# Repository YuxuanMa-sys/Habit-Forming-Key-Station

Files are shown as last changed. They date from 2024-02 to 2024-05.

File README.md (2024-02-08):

# Habit Forming Key Station

# Problem

People have a difficult time building habits. Specifically, a common issue that many have is losing or misplacing their keys/wallet whenever they enter their place of residence. If they were accustomed to placing and grabbing their keys from a specific designated location, then the likelihood of losing their keys and wallet would be significantly low.

# Solution

Our solution utilizes negative reinforcement to build positive habits for its users. We will build a designated station for placing one’s keys, or any small item of their choosing, when entering or leaving their home. It will begin detecting the proximity of the keys a few minutes after the keys have initially been removed from the dish, indicating the resident is not home. Once the resident returns home with the keys, a sensor should detect its presence with an RFID tag and continue ringing an alarm through a speaker until the keys are placed correctly. There will be a pressure sensor at the bottom of the dish that will indicate whether the keys have been put into the device. Our solution will have 5 subsystems: proximity detection, control and processing, alarm, confirmation, and power. 

Team members:

- [Ali Husain]
- [Cedric Mathew]
- [Marsh Ma]

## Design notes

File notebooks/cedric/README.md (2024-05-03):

### Lab Entry: February 17, 2024 - Power Subsystem Initial Design and Testing
**Objective:** Design and test the Power Subsystem to ensure stable voltage supply for all components.

**Design Considerations:**
- Chose a power adapter capable of delivering 5V to 36V to accommodate various component needs.
- Integrated a voltage regulator (LM1117T-3.3) to step down voltage to 3.3V, necessary for microcontroller and sensor operations.

**Equations and Formulas:**
- Voltage Output: \( V_{out} = V_{in} \times \left(\frac{R2}{R1 + R2}\right) \) where \( V_{in} \) is the input from the power adapter, R1 and R2 are resistances in the voltage divider circuit.
  
**Bibliographic References:**
- LM1117 800-mA Low-Dropout Linear Regulator Datasheet, Texas Instruments. [Accessed: February 17, 2024].

**Testing and Debugging:**
- Setup included the power adapter connected to a breadboard with multimeter readings confirming output stability.
- Identified an issue with voltage fluctuation; added capacitors to stabilize output.

**Results and Analysis:**
- Post modification, stable 3.3V output achieved with ±0.05V tolerance.
- Test setup and multimeter readings documented for future reference.

### Lab Entry: February 28, 2024 - Alarm Subsystem Initial Design and Testing
**Objective:** Design and test the Alarm Subsystem to ensure it triggers appropriately when the user does not place keys in the designated area.

**Design Considerations:**
- Selected CMS-251472-24SP speaker for its optimal sound pressure level and frequency response for household environments.
- Integrated with ATtiny84A microcontroller to manage alarm logic based on input from the proximity detection subsystem.

**Equations and Formulas:**
- Sound Pressure Level (SPL) calculation to ensure audibility: \( SPL = 20 \log \left(\frac{P}{P_{ref}}\right) \) where \( P \) is the sound pressure and \( P_{ref} \) is the reference sound pressure.

**Bibliographic References:**
- CMS-251472-24SP Datasheet, CUI Devices. [Accessed: February 24, 2024].

**Testing and Debugging:**
- Alarm subsystem circuit set up on breadboard with connections to microcontroller and speaker.
- Tested alarm activation by simulating conditions where keys are not placed: alarm triggered as expected.

**Results and Analysis:**
- Alarm effectively audible at 80 dB across standard testing room, conforming to design specifications.
- Documented all testing setups, circuit diagrams, and results for inclusion in the final report.

### Lab Entry: March 21, 2024 - Further Testing of the Power Subsystem
**Objective:** Conduct extensive load testing on the Power Subsystem to ensure reliability under full operational conditions.

**Design Considerations:**
- Continued use of the initial power adapter and voltage regulator setup to evaluate long-term stability and performance under variable loads.

**Equations and Formulas:**
- Calculation of expected power draw: \( P = V \times I \), ensuring that total power does not exceed the capacity of the power adapter.

**Bibliographic References:**
- "Understanding Power Supplies and Simple Circuits," IEEE Spectrum, 2024. Provides insights into best practices for power stability and efficiency.

**Testing and Debugging:**
- Setup included multiple components drawing power simultaneously to simulate real-world usage.
- Monitored voltage drops and regulator heat dissipation over extended periods.

**Results and Analysis:**
- Observed minimal voltage fluctuation within acceptable limits of ±0.1V during extended testing.
- Heat dissipation was within safe limits; however, noted the need for potential heat sinks if ambient temperatures increase.

### Lab Entry: March 30, 2024 - Prototype Housing Development and Testing
**Objective:** Design and test a prototype housing for the key station to enhance aesthetic appeal and functional reliability.

**Design Considerations:**
- Explore materials that are both aesthetically pleasing and functional, such as acrylic and ABS plastic, for the prototype housing.
- Design must accommodate all internal components securely while allowing easy access for maintenance and adjustments.

**Bibliographic References:**
- "Modern Materials for Product Design," Materials Today, 2024. Discusses the properties of various polymers and composites used in consumer electronics housing.

**Testing and Debugging:**
- Constructed an initial prototype using 3D-printed ABS plastic to assess fit and ease of assembly.
- Conducted drop tests and stress tests to evaluate the durability of the materials and the integrity of the housing.

**Results and Analysis:**
- The prototype housing adequately protected internal components from impacts and provided satisfactory thermal management.
- Identified issues with assembly alignment; adjustments to design tolerances were noted for the next prototype iteration.

### Lab Entry: April 6, 2024 - CAD Design Refinement and Component Layout
**Objective:** Refine the CAD design of the key station's housing to optimize space and improve component arrangement.

**Design Considerations:**
- Utilize CAD software to create detailed 3D models of the housing, ensuring all components fit precisely with efficient use of space.
- Design features such as snap-fit connections for easier assembly and maintenance.

**Equations and Formulas:**
- Calculation of enclosure dimensions based on component sizes and necessary clearances: \( V = l \times w \times h \) where \( l, w, h \) are the length, width, and height of the housing.

**Bibliographic References:**
- "CAD Techniques in Modern Product Design," Journal of Engineering and Industrial Design, 2024. Discusses advanced CAD modeling strategies for electronic enclosures.

**Testing and Debugging:**
- Digital simulations of the assembly process to identify potential interference or alignment issues.
- Stress analysis on critical points to ensure the structure can withstand everyday use.

**Results and Analysis:**
- Adjustments made to the internal layout to reduce interference and improve airflow around heat-generating components.
- Identified the need for additional supports around the snooze button and speaker areas to prevent flexing during use.

### Lab Entry: April 9, 2024 - Prototype Iteration and User Interface Design
**Objective:** Iterate on the prototype design based on initial feedback and integrate user interface elements for better usability.

**Design Considerations:**
- Enhance the visual and tactile aspects of the user interface, such as the snooze button and LED indicators, using CAD to model these features precisely.
- Incorporate feedback mechanisms visually represented in the CAD model to assist with user interaction.

**Bibliographic References:**
- "Ergonomics in Design: User Interface and Aesthetics," Human Factors and Ergonomics, 2024. Provides guidelines for designing user-friendly interfaces and controls.

**Testing and Debugging:**
- Conduct user testing with the new prototype to gather feedback on the interface and overall usability.
- Use CAD simulations to visualize operation sequences and ensure all moving parts operate without binding.

**Results and Analysis:**
- User feedback highlighted the need for larger, more tactile buttons and clearer LED indicators, which were incorporated into the design.
- CAD revisions made to improve ergonomics, reducing the force required to activate controls and enhancing user interaction comfort.

### Lab Entry: April 15, 2024 - Final Power System Redesign
**Objective:** Implement a final redesign of the Power Subsystem due to issues with the original power adapter and to accommodate changes in voltage requirements.

**Design Considerations:**
- Switched to using an Arduino Uno as a stable 5V power source after the power adapter failed to provide consistent outputs.
- Adjusted voltage requirements across subsystems to ensure compatibility with the Arduino's output capabilities.

**Equations and Formulas:**
- Verification of power supply requirements: \( I = \frac{P}{V} \), where \( P \) is power in watts, \( V \) is voltage in volts, and \( I \) is current in amperes. This equation ensures that the Arduino can sufficiently power all subsystems without exceeding its current limitations.

**Bibliographic References:**
- Arduino Power Supply Capabilities, Arduino Official Documentation, 2024.

**Testing and Debugging:**
- Re-tested the entire system using the Arduino to ensure all subsystems function correctly with the new power setup.
- Monitored system stability and temperature to assess the impact of continuous operation on the Arduino.

**Results and Analysis:**
- The Arduino provided a stable and reliable power source, with all subsystems operating within normal parameters.
- Noted improvements in system reliability and a reduction in complexity by eliminating the external power adapter.

### Lab Entry: April 17, 2024 - Final System Assembly and Verification Testing
**Objective:** Assemble the final version of the habit-forming key station and conduct comprehensive verification testing to validate all design requirements and functionality.

**Design Considerations:**
- Integrated all subsystems within the newly designed housing, ensuring secure mounting and optimal placement for user interaction.
- Enhanced the alarm subsystem by switching from a traditional speaker to a piezo buzzer for better reliability and integration on the breadboard setup.

**Bibliographic References:**
- "Standards for Electronic Test and Verification," IEEE Standard Association, 2024.

**Testing and Debugging:**
- Conducted a series of stress tests, including power cycling and long-duration operational tests, to ensure durability and reliability.
- Systematic testing of the proximity detection, alarm functionality, and user interface responsiveness.

**Results and Analysis:**
- All subsystems met or exceeded their performance criteria, with successful integration demonstrated through seamless operation during testing.
- Feedback from user trials was overwhelmingly positive, with particular praise for the system's responsiveness and reliability.

**Additional Notes:**
- Prepared detailed documentation of all tests, including setups, results, and any anomalies, for inclusion in the final project report.
- Developed a user manual based on the testing outcomes and operational characteristics of the key station.

## Lab Entry: April 20, 2024 - Preparation of Presentation and Final Paper Outlines
### Objective
Develop comprehensive outlines for an upcoming presentation and the final project report, summarizing the project's scope, key findings, and conclusions.

### Design Considerations
- Organize content to flow logically, beginning with an introduction to the problem statement, followed by a detailed discussion of the design process, testing methodologies, and final outcomes.
- Emphasize key innovations, challenges overcome, and the practical applications of the habit-forming key station.

### Presentation Outline
1. **Introduction**
   - Overview of the project and its objectives.
   - Importance of key management and habit formation.

2. **Design Overview**
   - Description of the habit-forming key station and its components.
   - Detailed view of the subsystems: Power, Alarm, Proximity Detection, and Confirmation.

3. **Testing and Results**
   - Summary of testing phases for each subsystem.
   - Presentation of critical data and findings.
   - Discussion on the stability and efficiency improvements in the final design.

4. **Challenges and Solutions**
   - Highlight significant challenges faced during the design and testing phases.
   - Discuss the solutions implemented to overcome these challenges.

5. **Conclusion and Future Work**
   - Summary of the project’s impact on habitual behavior related to key placement.
   - Suggestions for future enhancements or related products.

6. **Q&A**
   - Open the floor for questions and provide thoughtful responses to engage the audience.

### Final Paper Outline
1. **Abstract**
   - Brief summary of the entire project and its outcomes.

2. **Introduction**
   - Detailed problem statement and the project's scope.

3. **Methodology**
   - Explanation of the design process and testing methodologies used.

4. **System Design**
   - Comprehensive details of each subsystem, including schematics and component specifications.

5. **Results**
   - Analysis of testing results, demonstrating the efficacy of the system.
   - Statistical data and graphs showcasing performance metrics.

6. **Discussion**
   - Interpretation of results.
   - Evaluation of the system’s performance against initial objectives.

7. **Challenges and Solutions**
   - Detailed account of obstacles encountered and their resolutions.

8. **Conclusion and Recommendations**
   - Conclusions drawn from the project.
   - Recommendations for future research and potential product development.

9. **References**
   - Cite all sources used in the research and development of the project.

### Testing and Debugging
- Conduct peer reviews of the outlines to ensure completeness and clarity.
- Simulate the presentation to a small audience for feedback on content delivery and comprehension.

### Results and Analysis
- Adjustments made to the presentation content based on feedback, improving clarity and engagement.
- Finalization of the paper outline to ensure it meets academic standards and thoroughly documents the project lifecycle.

### Additional Notes
- Prepare visual aids and supplementary materials for the presentation to enhance audience understanding.
- Schedule further review sessions to refine the presentation delivery and ensure all team members are prepared.

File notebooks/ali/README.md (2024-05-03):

# Ali's Lab Notebook

## Project Overview
**Team Members:** Cedric Mathew, Ali Husain, Marsh Ma  
**Professor:** Arne Fliflet  
**TA:** Abhisheka Mathur Seka  

# 2024-01-25 - Brainstorming Session
**Ideas for our project**

1. Gesture ring - control your phone using a ring on your finger
2. Shower / Bath temperatur reader - figure out the temperature of your shower for accurate reading
3. Habit Forming Key Dish - Stop losing your keys at home. Keep them in one place

# 2024-02-10 - Figuring out parts for our design

This section details the role and functionality of each key component utilized in the Habit Forming Key Station project.

## ATtiny84A - Microcontroller (Microchip Technology)

- **Function:** Serves as the central processing unit of the project, managing input from sensors and controlling output to various devices. It executes the embedded software that dictates the behavior of the system, including signal processing, decision making, and communication with other electronic components.
- **Cost:** $1.62

## CMS-251472-24SP - Speaker (CUI Devices)

- **Function:** Outputs audible signals as part of the user interface. It can be used to provide feedback when a key is detected, alert users of system states, or issue warnings.
- **Cost:** $1.19

## SEN-09376 - Pressure Sensor (Interlink Electronics)

- **Function:** Measures the weight of the keys placed on the sensor to confirm their presence. This component is crucial for the Confirmation Subsystem, which detects and verifies the specific weight range of keys to activate or deactivate system features.
- **Cost:** $12.50

## L6R12-120 - Power Adapter (Tri-Mage, LLC)

- **Function:** Provides a stable power supply to the system, converting AC power from a standard wall outlet to a regulated DC voltage suitable for the electronics.
- **Cost:** $10.08

## LM1117T-3.3 - Voltage Regulator (Texas Instruments)

- **Function:** Ensures that the electronic components receive a constant, stable voltage despite variations in input power. This helps protect sensitive components and ensures reliable operation.
- **Cost:** $1.69

## DWM1000 - RF Transceiver (Qorvo)

- **Function:** Facilitates wireless communication within the system, particularly in the Proximity Detection Subsystem. This component is used to measure the distance to and from the key fob, enabling the system to detect when the keys are within a predefined range.
- **Cost:** $17.50

## COM-10440 ROHS - Button (Sparkfun)

- **Function:** Acts as a user interface element for manual input, allowing users to interact directly with the system, such as confirming an action or resetting the system state.
- **Cost:** $2.25

## CAB-14166 ROHS - Wire for Button (Sparkfun)

- **Function:** Connects the button to the microcontroller, providing the physical link through which button presses can be detected and processed by the system.
- **Cost:** $2.10

This lab notebook documents the design, development, and testing of the Habit Forming Key Station, focusing on sourcing and ordering parts and detailing the control and processing subsystem.

## January 20th - February 3rd
**Objective:** Identify and order necessary components for the initial prototype.

**Activities:**
- Conducted a component feasibility study to ensure availability and compatibility with our design requirements.
- Placed orders for the following parts:
  - ATmega328P microcontrollers from Microchip Technology, selected for their ease of use and extensive support in the hobbyist community.
  - Basic electronic supplies such as resistors, capacitors, and breadboards from Digikey.
  - Specialty sensors and input devices from Mouser Electronics.

**Decisions:**
- Opted for Arduino Uno for early phase testing due to its widespread use and support for rapid prototyping.
- Selected suppliers based on delivery times, cost, and component quality.

**Challenges:**
- Some parts were on backorder (button), requiring us to find alternative suppliers or adjust our design specifications slightly.

**Figures:**
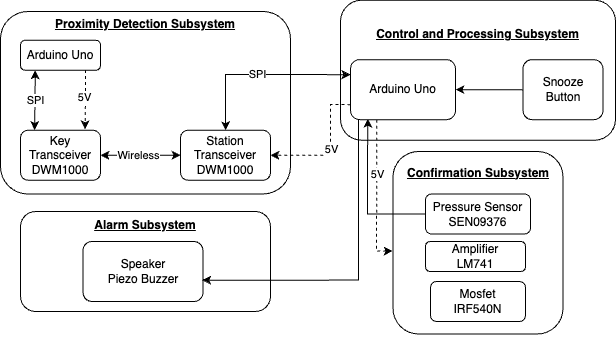
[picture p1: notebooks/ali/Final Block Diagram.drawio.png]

- Figure 1: Block diagram of the design we created

### March 1st - March 14th
**Objective:** Begin assembly and initial testing of the control and processing subsystem.

**Activities:**
- Assembled the basic circuit on a breadboard integrating the Arduino Uno with the ATmega328P.
- Conducted initial tests to ensure basic functionality, such as reading from the pressure sensor and activating the alarm based on sensor input.

**Issues Faced:**
- Integration issues between the pressure sensor and the Arduino required troubleshooting the circuit connections and modifying resistor values.
- Delays in part delivery disrupted our planned schedule.

**Diagrams:**
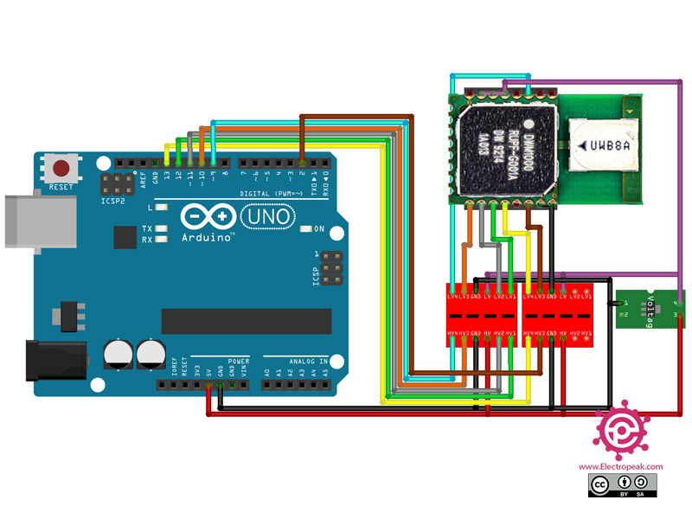
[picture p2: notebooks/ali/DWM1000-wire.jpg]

- Figure 2: Breadboard setup with labeled connections between the transceiver and arduino uno

### March 14th - March 28th
**Objective:** Finalize the control and processing subsystem and prepare for mid-term presentation.

**Activities:**
- Completed the integration of the control and processing subsystem with the proximity detection and alarm subsystems.
- Found transceiver issues with ranging library. Needed to do further testing to confirm this.

**Achievements:**
- Successfully demonstrated a working prototype during the mid-term review, receiving positive feedback and constructive critiques.

### April 2nd - April 15th
**Objective:** Complete final testing and prepare for project demonstration.

**Activities:**
- Conducted extensive reliability testing to ensure the system performs under various environmental conditions.
- Finalized the demonstration setup, practicing the sequence of operations and troubleshooting potential issues.

**Results:**
- The system consistently performed as expected across all tests, confirming readiness for the final presentation and demo.

**Demonstration Prep:**
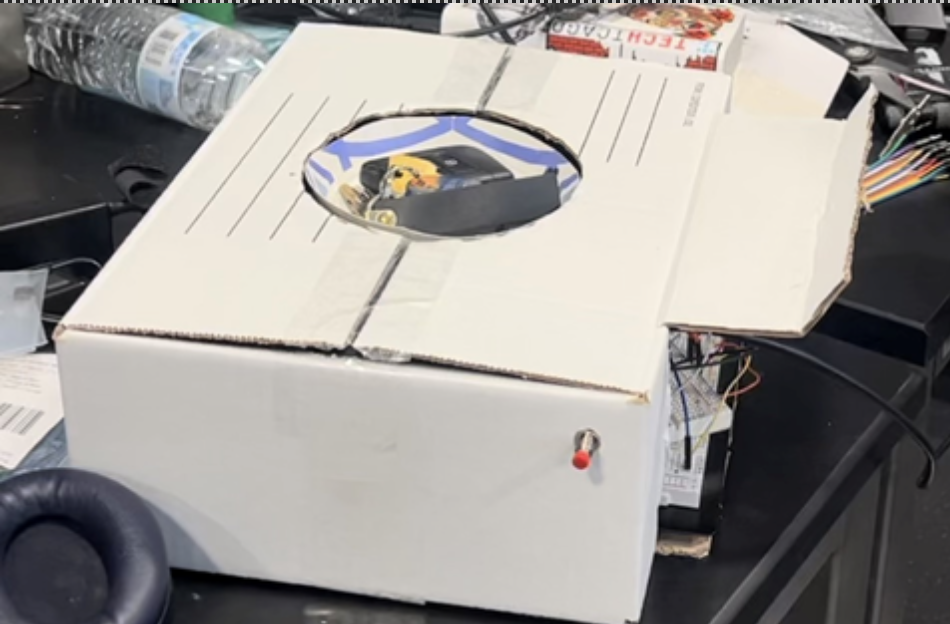
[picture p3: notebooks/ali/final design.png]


- Figure 6: Final project setup

---

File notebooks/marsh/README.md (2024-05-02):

# Marsh's Project Working Log: Habit Forming Key Station

## Table of Contents

1. [Initial PCB Design](#2024-03-05---initial-pcb-design)
2. [PCB Layout Adjustments](#2024-03-10---pcb-layout-adjustments)
3. [Confirmation Subsystem Component Tuning](#2024-03-27---confirmation-subsystem-component-tuning)
4. [Proximity Detection Subsystem Calibration](#2024-04-10---proximity-detection-subsystem-calibration)
5. [Integrated System Testing](#2024-04-15---integrated-system-testing)
6. [Performance Optimization](#2024-04-19---performance-optimization)
7. [Final Preparations and Revisions](#2024-04-21---final-preparations-and-revisions)

# 2024-03-05 - Initial PCB Design

Activities:

* Began initial design of the PCB tailored for supporting both subsystems.
* Selected and placed components on the schematic, focusing on a compact and efficient layout.

Progress:

* Completed the initial draft of the PCB schematic.

Changes Made:

* Switched from using a general-purpose microcontroller to a more power-efficient model better suited for real-time processing requirements.

# 2024-03-10 - PCB Layout Adjustments

Activities:

* Adjusted the PCB layout to optimize the routing of traces for power distribution and signal integrity.

Progress:

* Identified optimal trace widths and clearances to minimize noise and cross-talk between high-frequency components.

Changes Made:

* Moved the location of the power regulator to reduce electromagnetic interference with the Proximity Detection Subsystem.

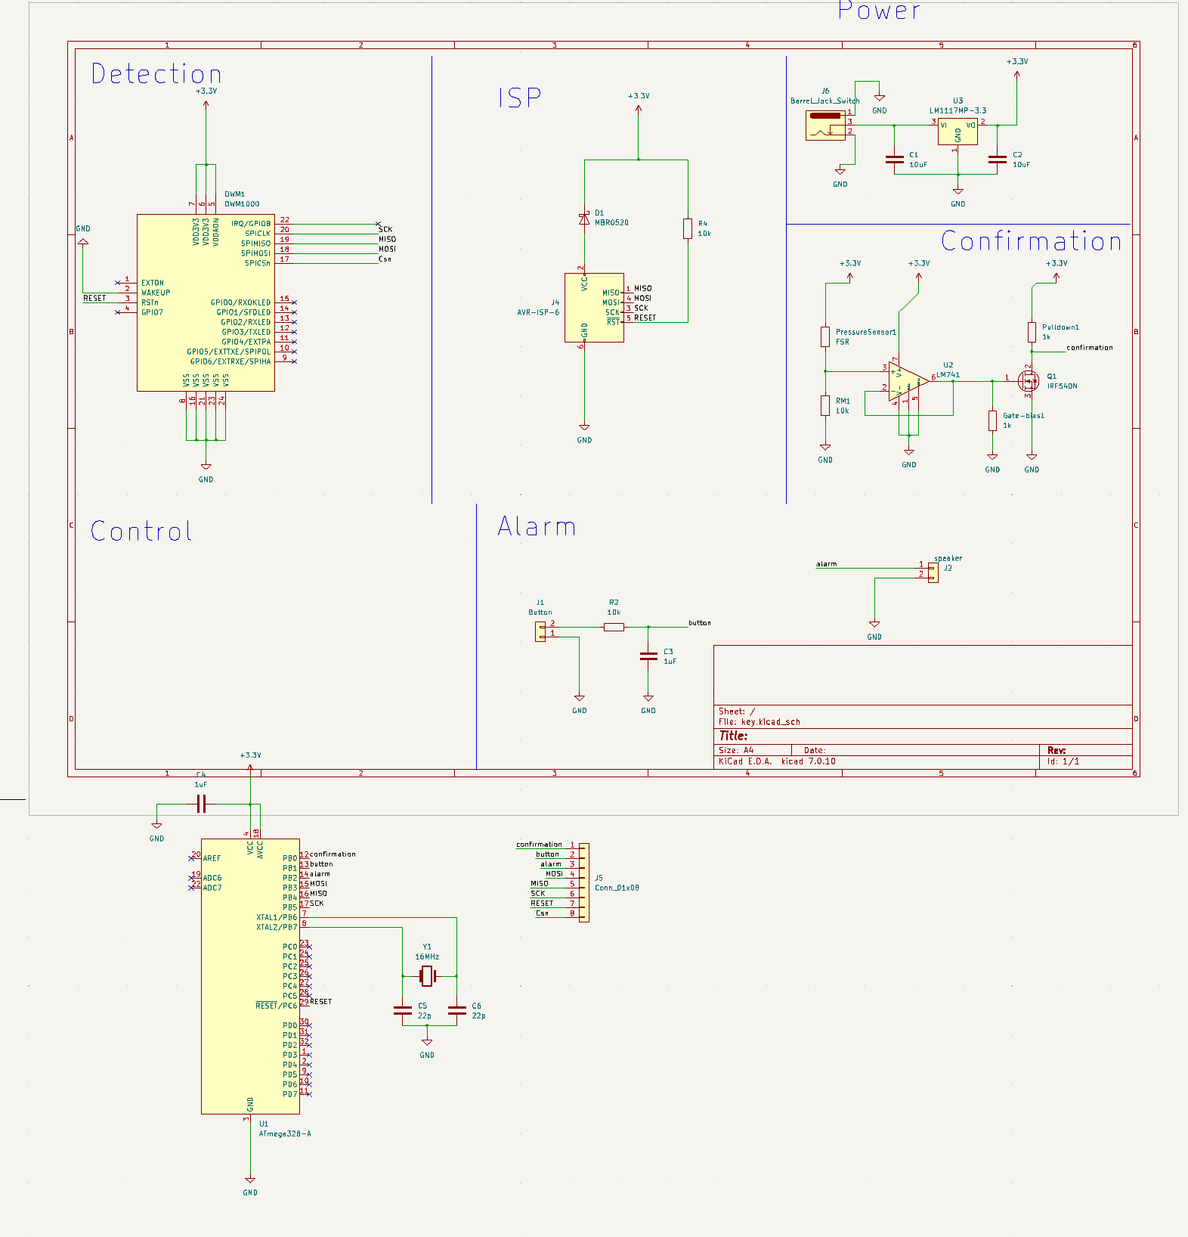
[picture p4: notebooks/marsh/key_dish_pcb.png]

This the schematic of our keydish PCB design

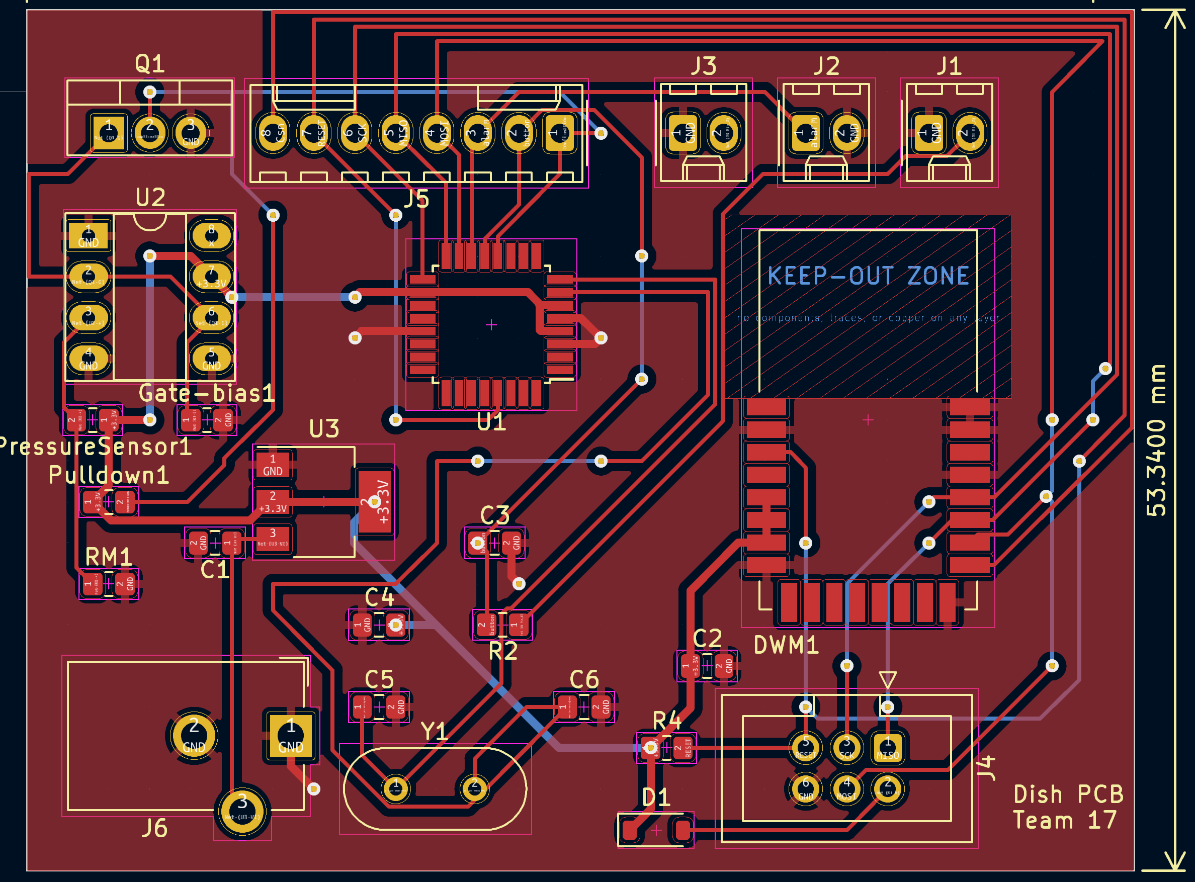
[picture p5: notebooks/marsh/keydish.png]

Front-side of our Keydish PCB design

And here are the schematic and front-side view of our keychain PCB:

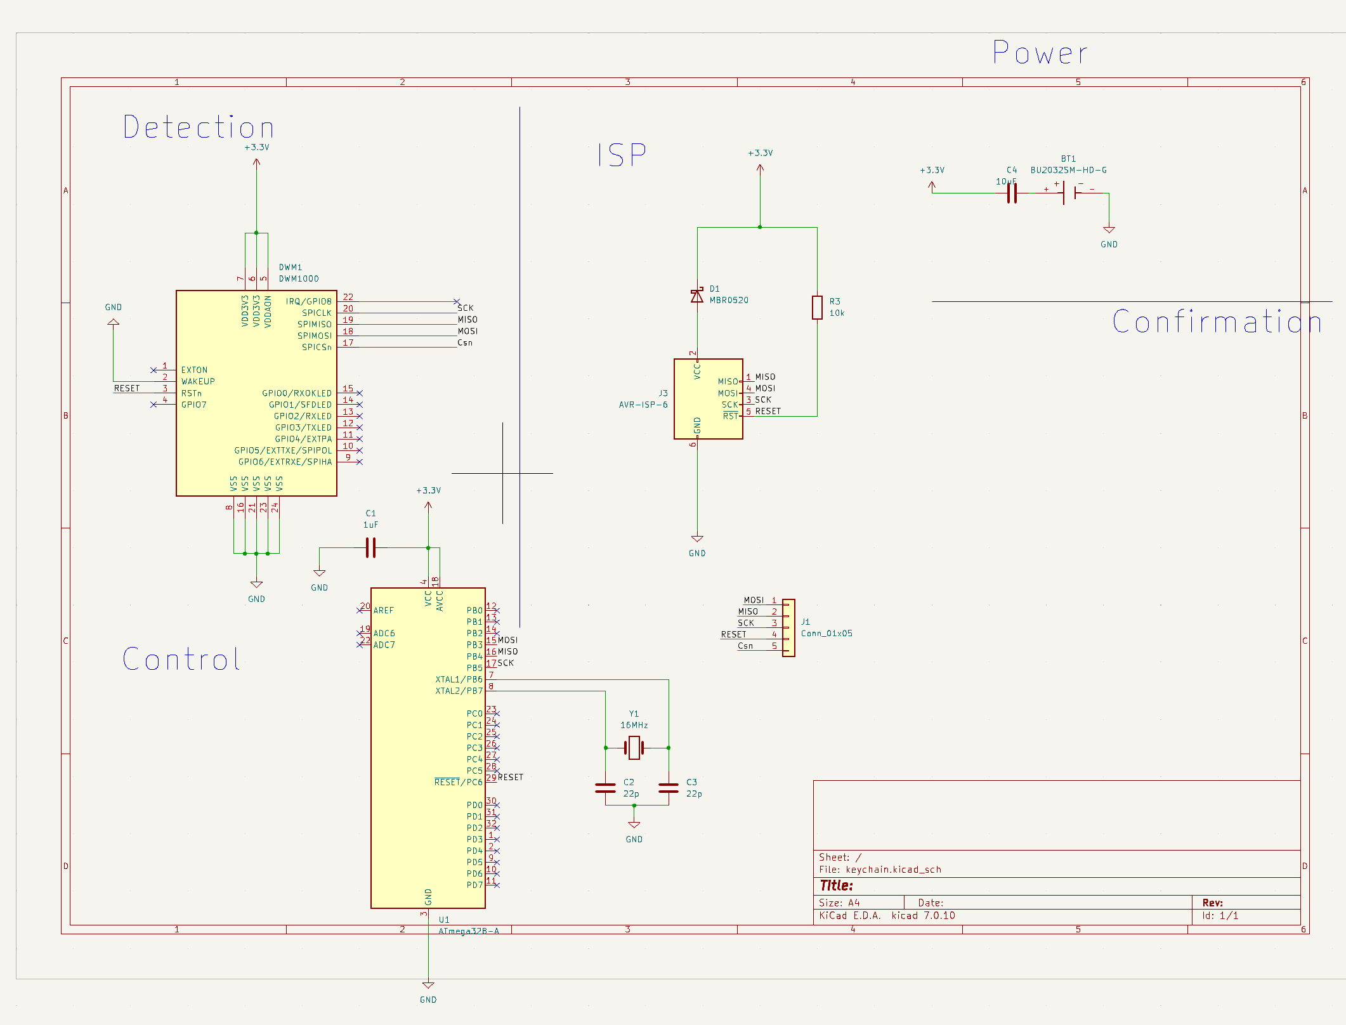
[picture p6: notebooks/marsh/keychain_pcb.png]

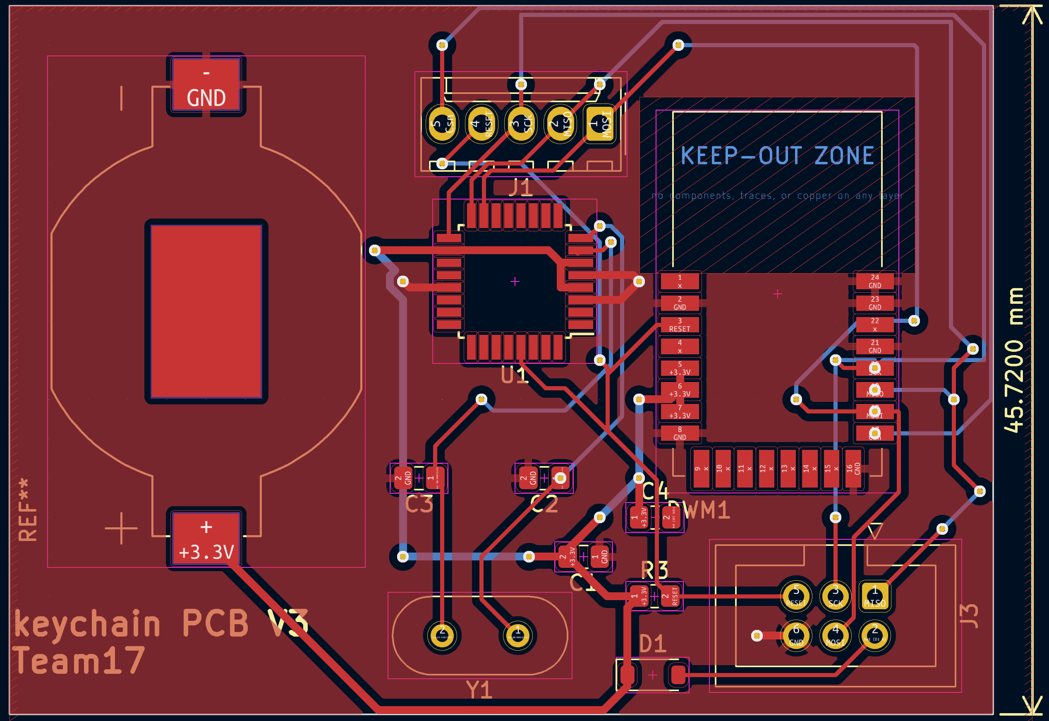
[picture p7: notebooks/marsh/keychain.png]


# 2024-03-27 - Confirmation Subsystem Component Tuning

We are using [FSR 406](https://www.interlinkelectronics.com/fsr-406) as our pressure sensor. 

[operational amplifier](https://www.ti.com/lit/ds/symlink/lm741.pdf)

[MOSFET](https://media.digikey.com/pdf/Data%20Sheets/Fairchild%20PDFs/IRF540N.pdf)

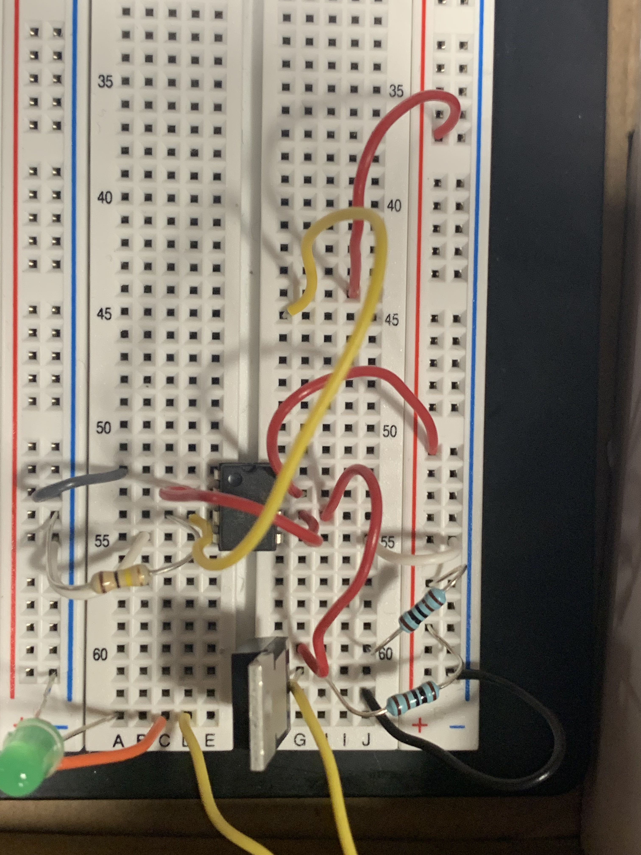
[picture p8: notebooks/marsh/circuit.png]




Activities:

* Tuned the voltage divider settings and integrated additional circuit components to enhance the detection accuracy of the FSR 406 sensor in the Confirmation Subsystem. Reviewed the force-resistance characteristics and voltage response graphs to optimize the resistor value for our specific application of detecting key weights between 45g and 55g.



Technical Insights:

* The resistance versus force graph provided in the sensor's datasheet was instrumental in understanding how the FSR 406's resistance decreases logarithmically as applied force increases. This insight was crucial for accurately setting up our voltage divider circuit.
* From the voltage output versus force graph for various RM values, we identified that a 100K Ohms resistor provided the optimal sensitivity and voltage output for our target range of 45g to 55g. This selection ensures that small changes in force within this narrow range result in discernible voltage changes, suitable for reliable key detection.




Circuit Integration:

* To further enhance the signal processing, an operational amplifier (op-amp) was added to the circuit. This op-amp serves to amplify the voltage output from the voltage divider, providing a stronger and more stable signal for the microcontroller to process.
* A MOSFET was incorporated to act as a switch controlled by the output voltage from the op-amp. This setup allows the circuit to trigger other system actions, such as turning off an alert or activating a status LED, once the keys are detected on the sensor.

Progress:

* The finalized circuit configuration, including the FSR 406 with a 100K Ohms RM, op-amp for signal amplification, and MOSFET for effective load switching, was tested with simulated key weights. The tests confirmed the circuit's capability to accurately and consistently detect weights within the specified range.

Challenges:

* Balancing the amplification level to avoid saturation while ensuring the circuit remains responsive to the designated force range was a complex task. Initial configurations required adjustments to the op-amp gain settings to achieve this balance.

Changes Made:

* Finalized the RM value at 100K Ohms after testing various configurations, which proved to be most effective for our application range.
Adjusted the op-amp gain and refined the MOSFET triggering threshold to improve the overall responsiveness and reliability of the system.

Next Steps:

* Implement a series of long-duration stability tests to ensure the circuit maintains its accuracy and reliability over time and under different environmental conditions.
* Document the circuit design details, including schematics and component specifications, for the final project report and upcoming presentations.

# 2024-04-10 - Proximity Detection Subsystem Calibration

Activities:

* Calibrated the DWM1000 module to fine-tune distance measurement accuracy.

* Implemented firmware updates to optimize data transmission between the key fob and station.

Progress:

* Achieved a consistent detection accuracy within the range of less than 1% error.

Changes Made:

* Adjusted the UWB pulse frequency to enhance detection through obstacles.

To test the transcievers using arduino and breadboard, I designed an adaptor board for the transceiver, which is shown below

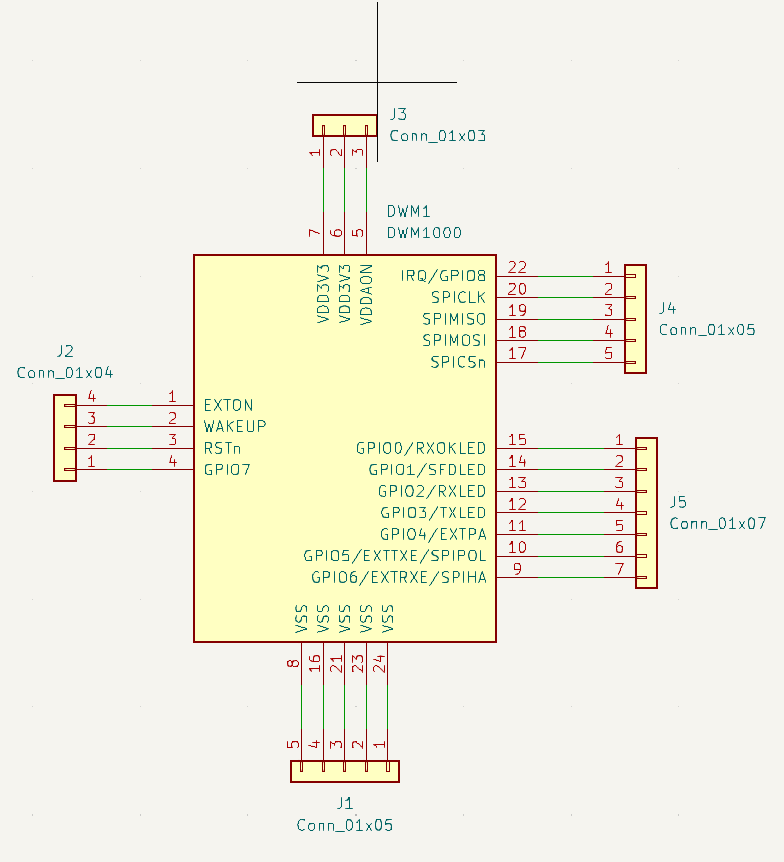
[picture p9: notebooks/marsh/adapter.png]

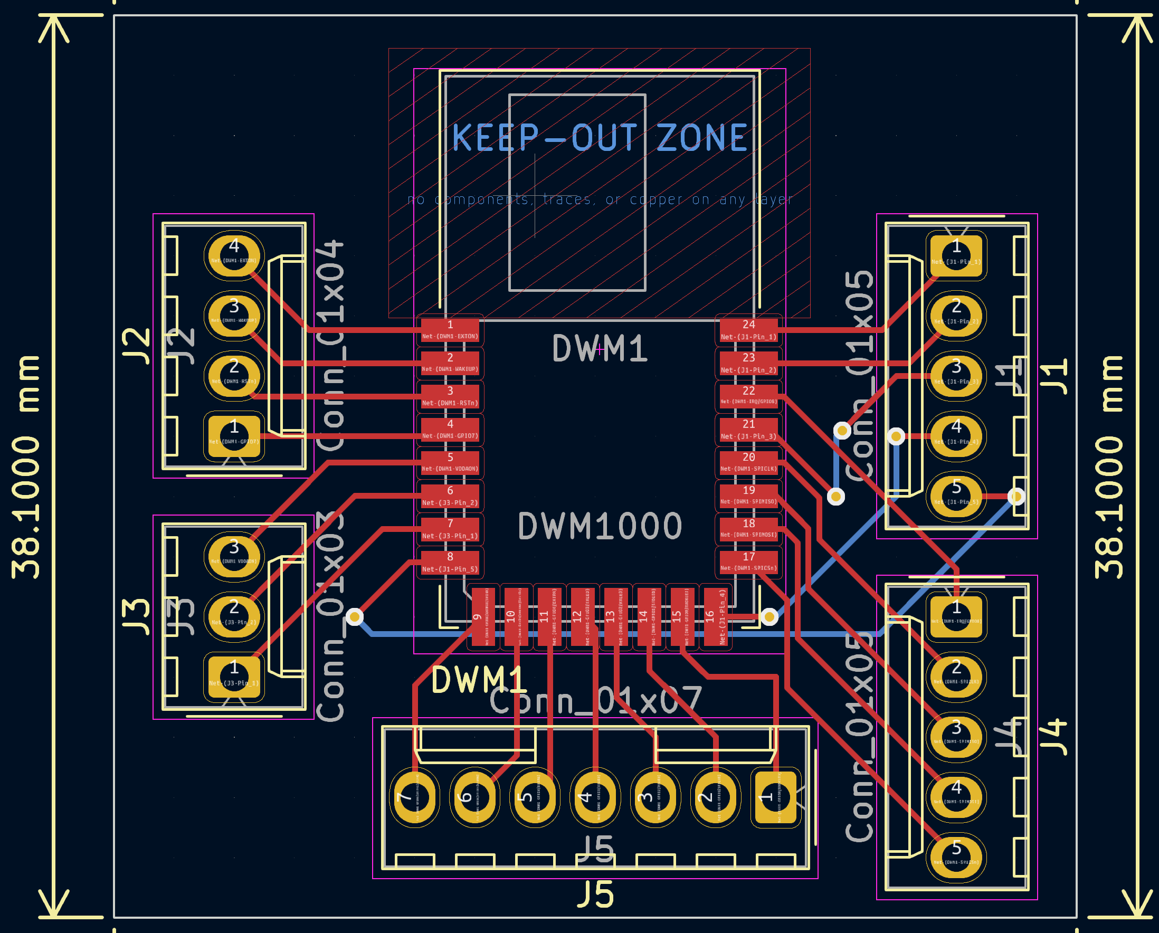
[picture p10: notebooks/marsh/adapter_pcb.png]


# 2024-04-15 - Integrated System Testing

Activities:

* Conducted integrated testing of both subsystems with the newly designed PCB to ensure compatibility and performance.

Progress:

* Both subsystems operated seamlessly with the new PCB layout.

Changes Made:

* Replaced the initial microcontroller firmware with a more robust version to handle edge cases in subsystem interactions.

# 2024-04-19 - Performance Optimization

Activities:

* Optimized the power management strategies to enhance the overall system's energy efficiency.

Progress:

* Reduced power consumption by 10% without compromising subsystem performance.

Changes Made:

*Integrated a new sleep mode protocol into the firmware to reduce idle power draw.

# 2024-04-21 - Final Preparations and Revisions

Activities:

* Made final adjustments to the subsystems based on feedback from trial runs.
* Prepared the documentation and presentation materials for project demonstration.

Progress:

* System is fully operational with all functionalities meeting the project's specifications.

Changes Made:

* Increased the robustness of the Confirmation Subsystem against false positives by refining the threshold settings.



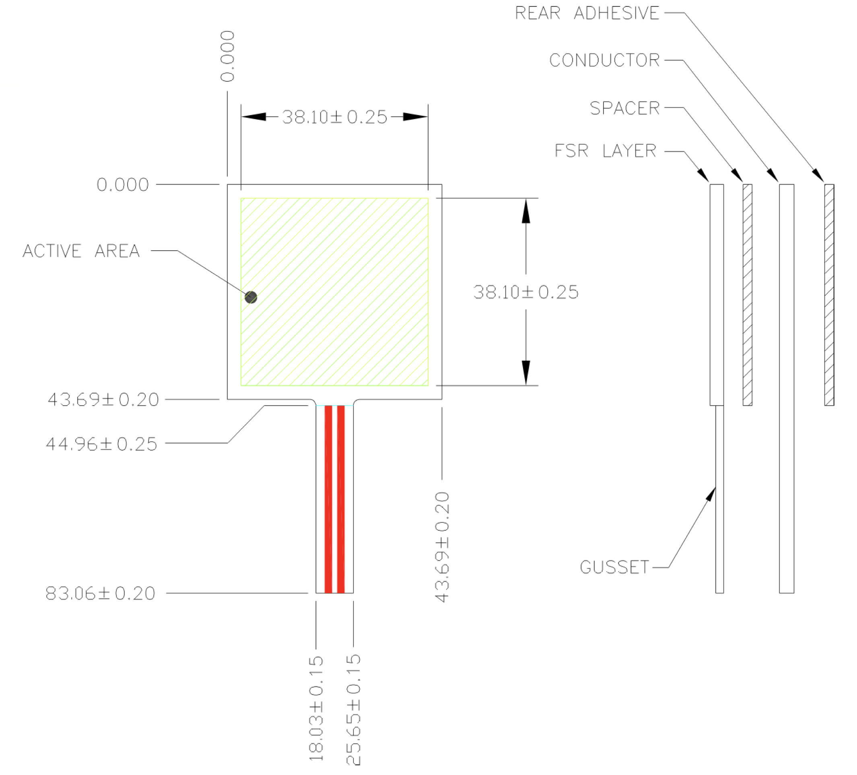
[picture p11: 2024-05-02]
notebooks/marsh/sensor-layout.png

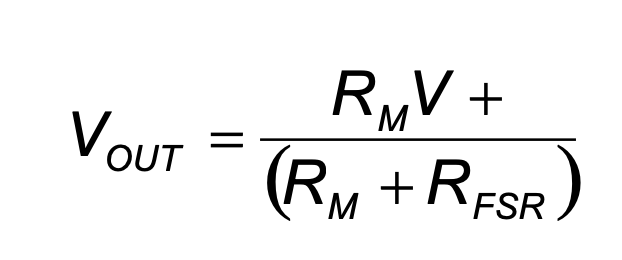
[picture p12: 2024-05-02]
notebooks/marsh/sensor-equation.png

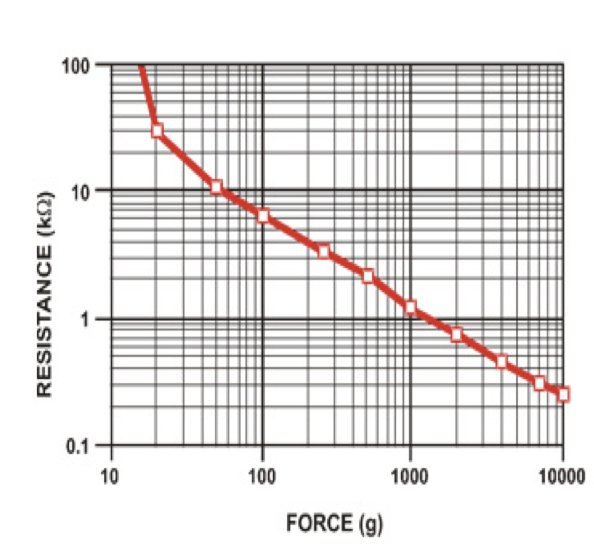
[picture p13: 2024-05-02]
notebooks/marsh/force-curve.png

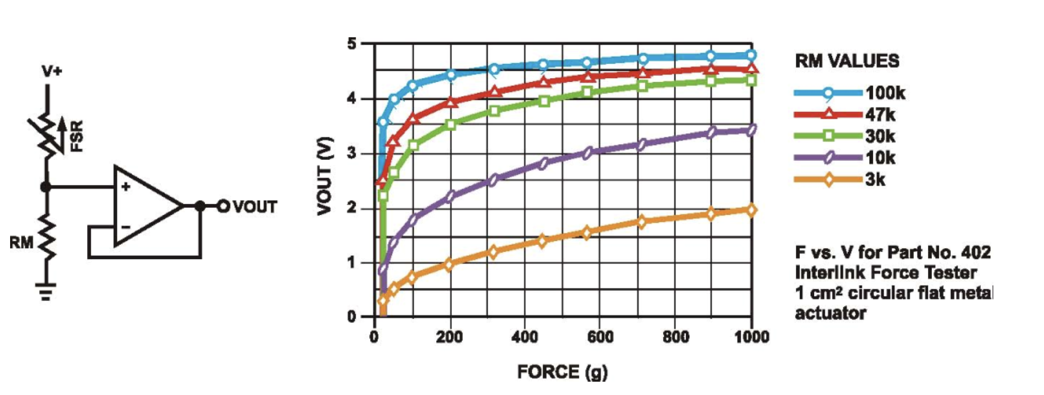
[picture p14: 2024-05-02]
notebooks/marsh/sensor-curve.png

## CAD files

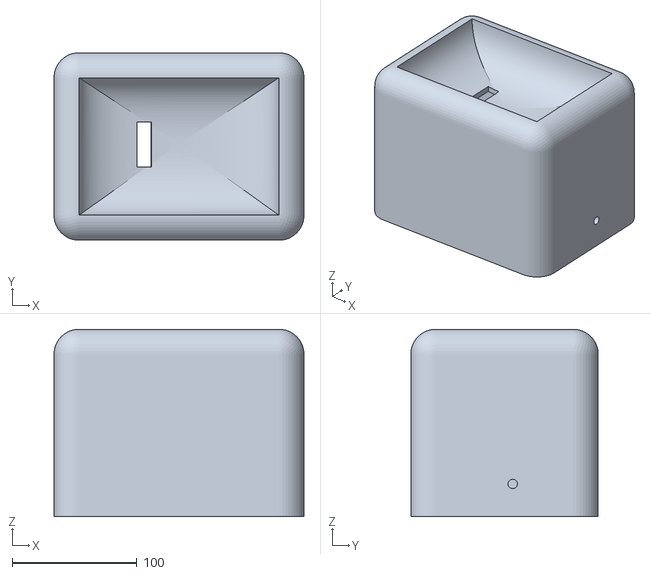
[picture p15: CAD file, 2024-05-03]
notebooks/cedric/keystation better v2.stl
200.0 x 150.0 x 150.0

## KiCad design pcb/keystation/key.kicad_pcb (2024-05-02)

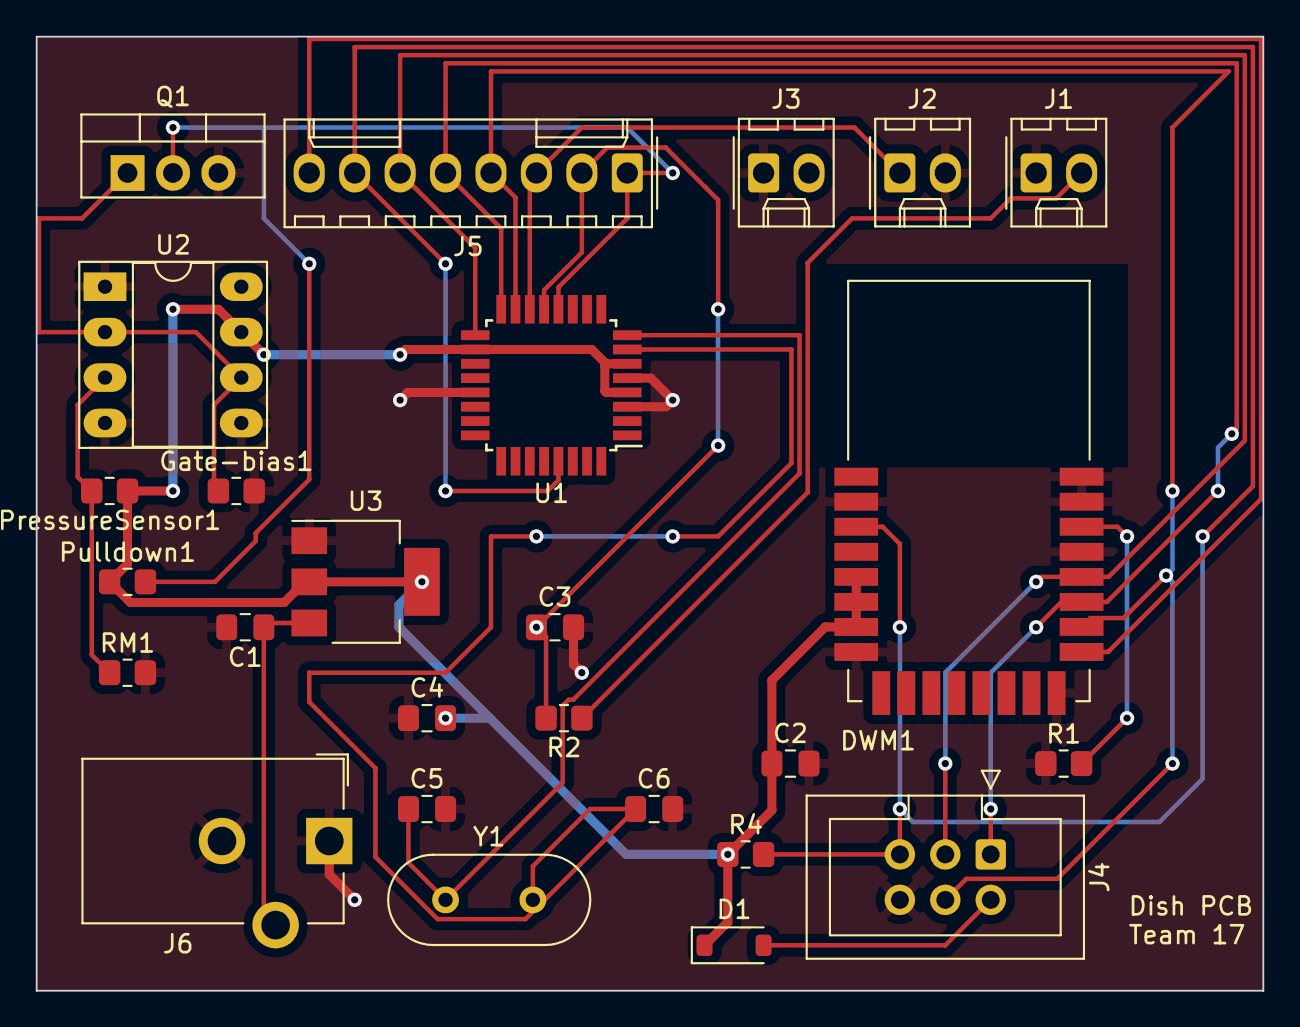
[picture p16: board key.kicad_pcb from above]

Board: 2 copper layers, 68.6 x 53.3 mm, 26 parts (0 on the bottom side), 17 nets.

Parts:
C1, C2: 10uF; C_0805_2012Metric_Pad1.18x1.45mm_HandSolder
C3, C4: 1uF; C_0805_2012Metric_Pad1.18x1.45mm_HandSolder
C5, C6: 22p; C_0805_2012Metric_Pad1.18x1.45mm_HandSolder
D1: MBR0520; D_SOD-123
DWM1: DWM1000
Gate-bias1: 1k; R_0805_2012Metric_Pad1.20x1.40mm_HandSolder
J1: Button; Molex_KK-254_AE-6410-02A_1x02_P2.54mm_Vertical
J2: speaker; Molex_KK-254_AE-6410-02A_1x02_P2.54mm_Vertical
J3: Vin; Molex_KK-254_AE-6410-02A_1x02_P2.54mm_Vertical
J4: AVR-ISP-6; IDC-Header_2x03_P2.54mm_Vertical
J5: Conn_01x08; Molex_KK-254_AE-6410-08A_1x08_P2.54mm_Vertical
J6: Barrel_Jack_Switch; BarrelJack_CUI_PJ-102AH_Horizontal
PressureSensor1: FSR; R_0805_2012Metric_Pad1.20x1.40mm_HandSolder
Pulldown1: 1k; R_0805_2012Metric_Pad1.20x1.40mm_HandSolder
Q1: IRF540N; TO-220-3_Vertical
R1: 100; R_0805_2012Metric_Pad1.20x1.40mm_HandSolder
R2, R4: 10k; R_0805_2012Metric_Pad1.20x1.40mm_HandSolder
RM1: 10k; R_0805_2012Metric_Pad1.20x1.40mm_HandSolder
U1: ATmega328-A; TQFP-32_7x7mm_P0.8mm
U2: LM741; DIP-8_W7.62mm_Socket_LongPads
U3: LM1117MP-3.3; SOT-223-3_TabPin2
Y1: 16MHz; Crystal_HC49-U_Vertical

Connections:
+3.3V: C2.1, C4.2, D1.1 (K), DWM1.5 (VDDAON), DWM1.6 (VDD3V3), DWM1.7 (VDD3V3), PressureSensor1.1, Pulldown1.1, R4.1, U1.4 (VCC), U1.6 (VCC), U1.18 (AVCC), U2.7 (V+), U3.2 (VO)
/Csn: DWM1.17 (SPICSn), J5.8
/MISO: DWM1.19 (SPIMISO), J4.1 (MISO), J5.5, U1.16 (PB4)
/MOSI: DWM1.18 (SPIMOSI), J4.4 (MOSI), J5.4, U1.15 (PB3)
/RESET: DWM1.3 (RSTn), J4.5 (~RST), J5.7, R4.2, U1.29 (~RESET/PC6)
/SCK: DWM1.20 (SPICLK), J4.3 (SCK), J5.6, U1.17 (PB5)
/alarm: J2.1, J5.3, U1.14 (PB2)
/button: C3.1, J5.2, R2.2, U1.13 (PB1)
/confirmation: J5.1, Pulldown1.2, Q1.2 (D), U1.12 (PB0)
GND: C1.2, C2.2, C3.2, C4.1, C5.2, C6.2, DWM1.2 (WAKEUP), DWM1.8 (VSS), DWM1.16 (VSS), DWM1.21 (VSS), DWM1.23 (VSS), DWM1.24 (VSS), Gate-bias1.2, J1.1, J2.2, J3.1, J4.6 (GND), J6.1, J6.2, Q1.3 (S), R1.1, RM1.2, U1.3 (GND), U1.5 (GND), U1.21 (GND), U2.1 (NULL), U2.4 (V-), U2.5 (NULL), U3.1 (GND)
unnamed: D1.2 (A), J4.2 (VCC)
unnamed: J1.2, R2.1
unnamed: Gate-bias1.1, Q1.1 (G), U2.2 (-), U2.6
unnamed: C6.1, U1.7 (XTAL1/PB6), Y1.2
unnamed: C5.1, U1.8 (XTAL2/PB7), Y1.1
unnamed: PressureSensor1.2, RM1.1, U2.3 (+)
unnamed: C1.1, J6.3, U3.3 (VI)

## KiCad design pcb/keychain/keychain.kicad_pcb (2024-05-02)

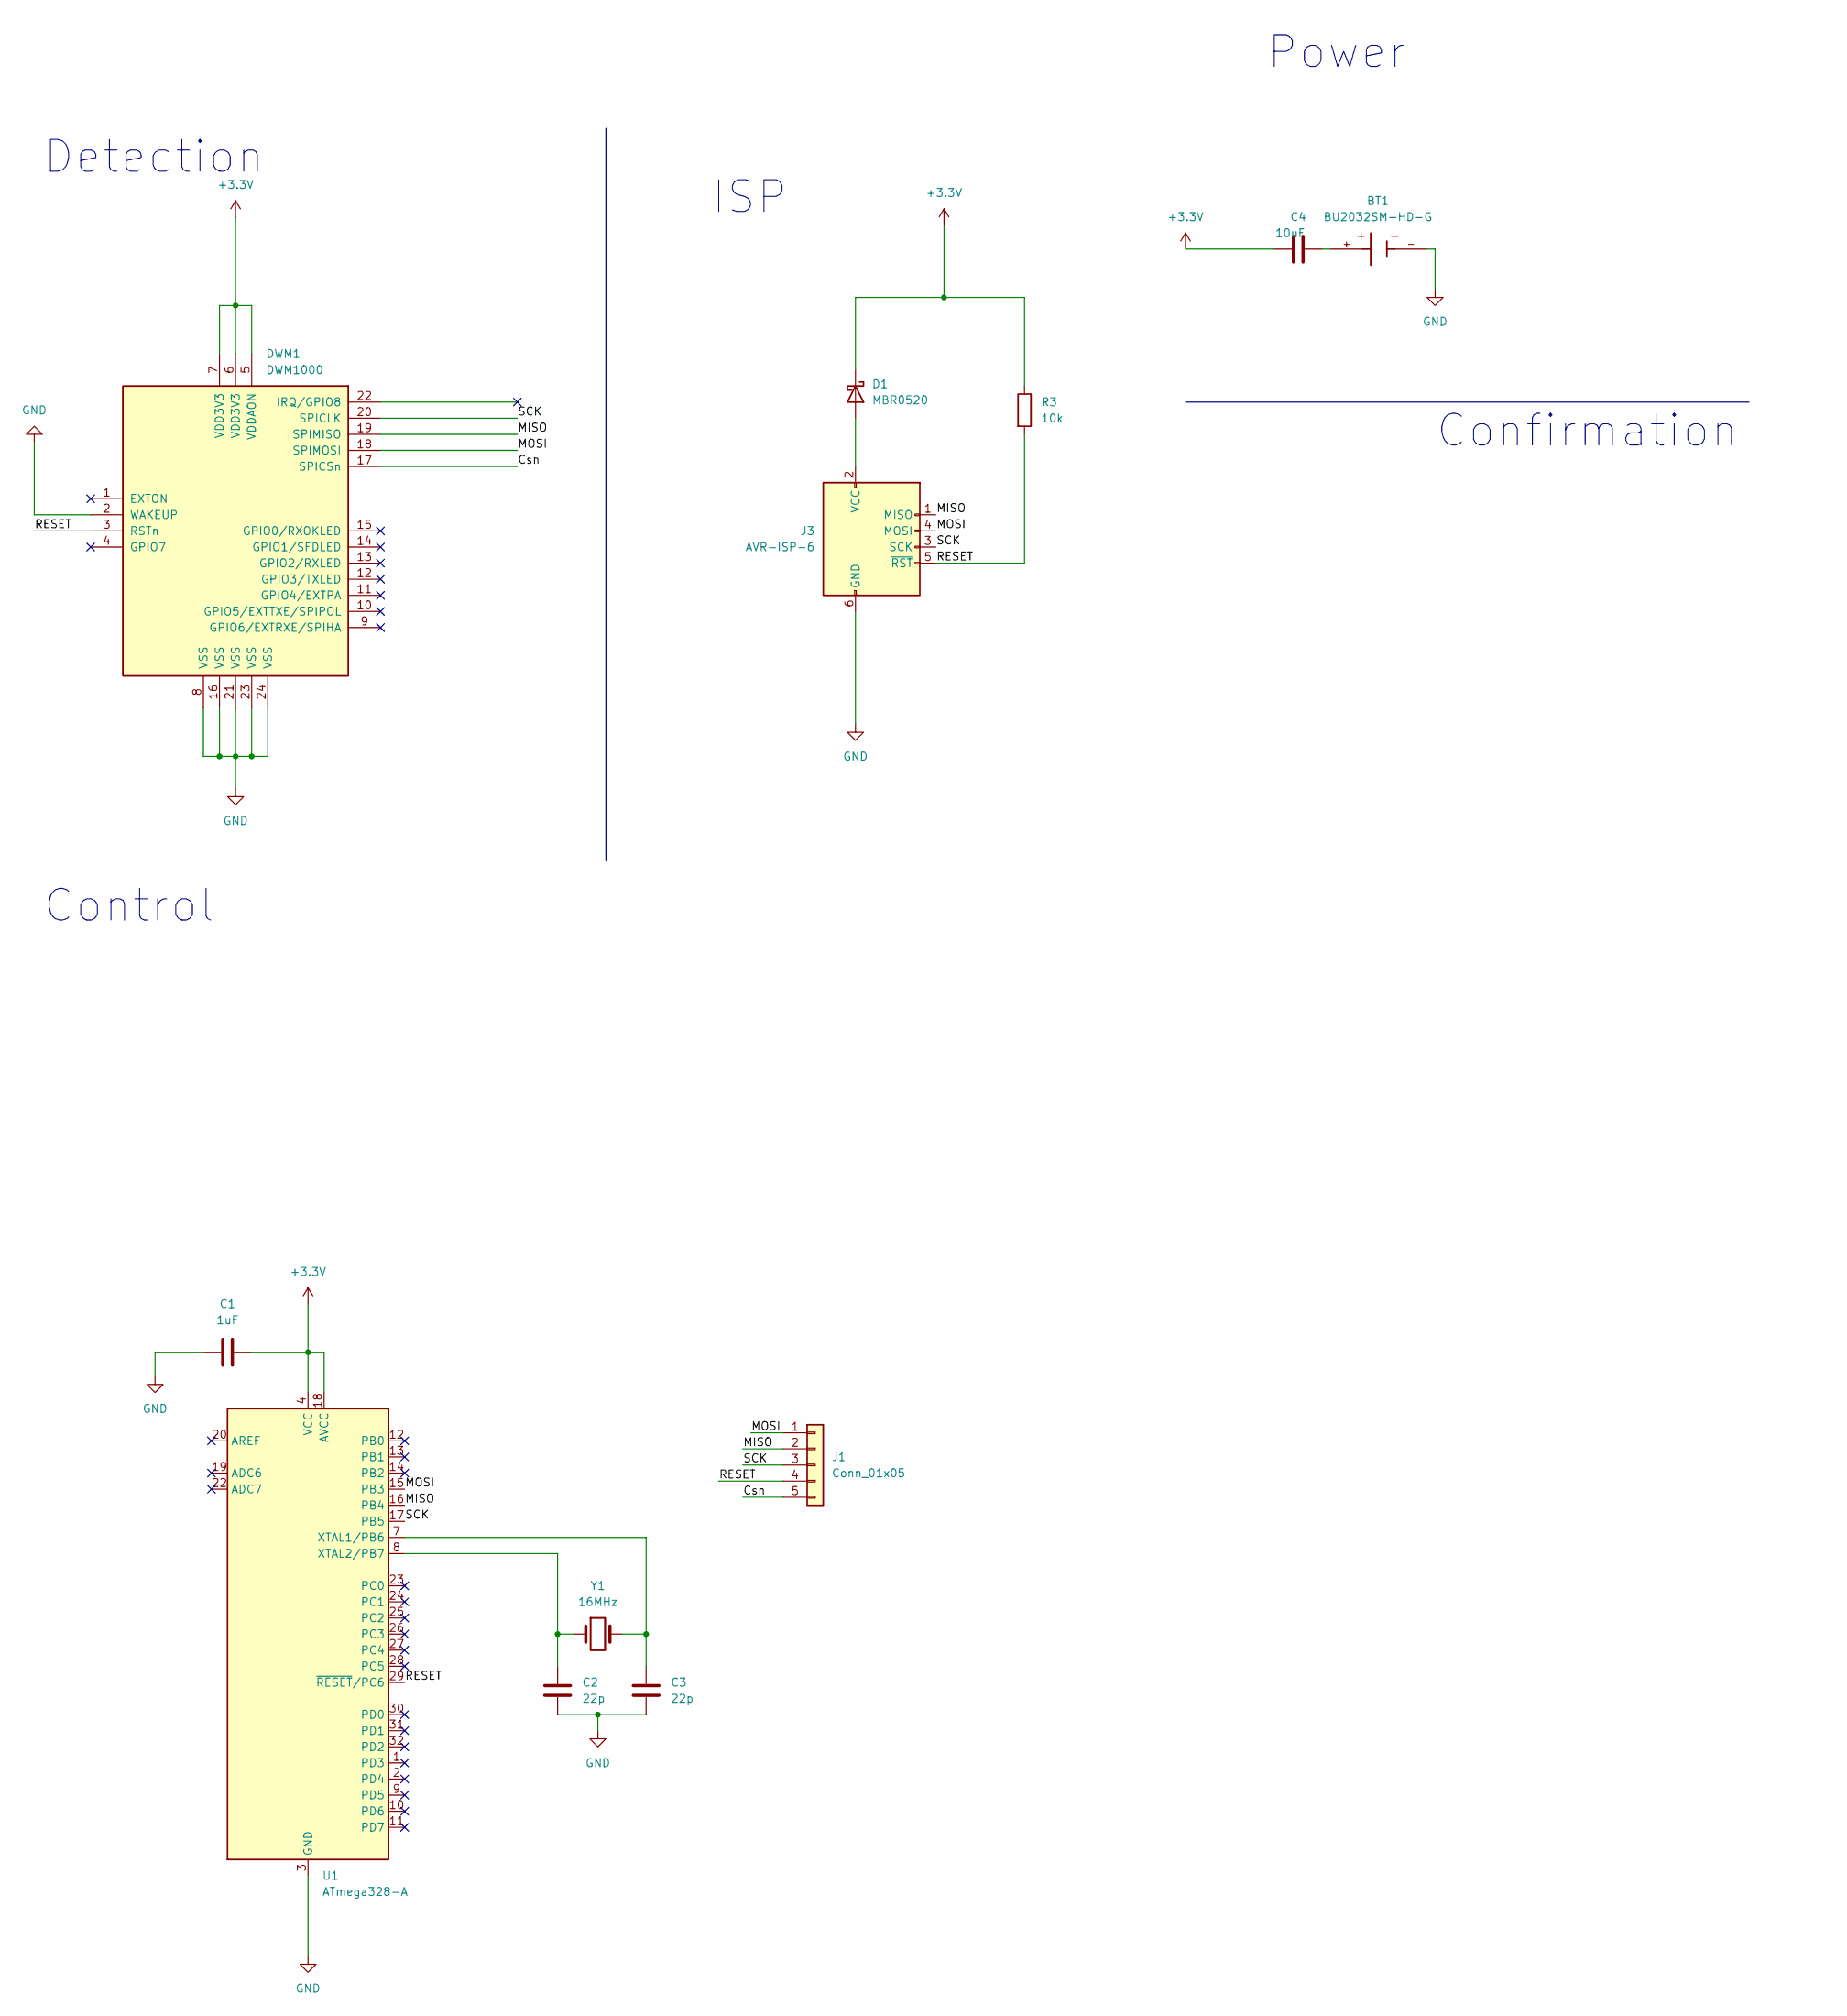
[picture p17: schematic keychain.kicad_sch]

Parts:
BT1: BU2032SM-HD-G; BAT_BU2032SM-HD-G; PARTREV 01/27/17
C1: 1uF; C_0805_2012Metric_Pad1.18x1.45mm_HandSolder
C2, C3: 22p; C_0805_2012Metric_Pad1.18x1.45mm_HandSolder
C4: 10uF; C_0805_2012Metric_Pad1.18x1.45mm_HandSolder
D1: MBR0520; D_SOD-123
DWM1: DWM1000
J1: Conn_01x05; Molex_KK-254_AE-6410-05A_1x05_P2.54mm_Vertical
J3: AVR-ISP-6; IDC-Header_2x03_P2.54mm_Vertical
R3: 10k; R_0805_2012Metric_Pad1.20x1.40mm_HandSolder
U1: ATmega328-A; TQFP-32_7x7mm_P0.8mm
Y1: 16MHz; Crystal_HC49-U_Vertical

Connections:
+3.3V: C1.2, C4.1, D1.1 (K), DWM1.5 (VDDAON), DWM1.6 (VDD3V3), DWM1.7 (VDD3V3), R3.1, U1.4 (VCC), U1.6 (VCC), U1.18 (AVCC)
/Csn: DWM1.17 (SPICSn), J1.5
/MISO: DWM1.19 (SPIMISO), J1.2, J3.1 (MISO), U1.16 (PB4)
/MOSI: DWM1.18 (SPIMOSI), J1.1, J3.4 (MOSI), U1.15 (PB3)
/RESET: DWM1.3 (RSTn), J1.4, J3.5 (~RST), R3.2, U1.29 (~RESET/PC6)
/SCK: DWM1.20 (SPICLK), J1.3, J3.3 (SCK), U1.17 (PB5)
GND: BT1.-, C1.1, C2.2, C3.2, DWM1.2 (WAKEUP), DWM1.8 (VSS), DWM1.16 (VSS), DWM1.21 (VSS), DWM1.23 (VSS), DWM1.24 (VSS), J3.6 (GND), U1.3 (GND), U1.5 (GND), U1.21 (GND)
unnamed: BT1.+, C4.2
unnamed: D1.2 (A), J3.2 (VCC)
unnamed: C3.1, U1.7 (XTAL1/PB6), Y1.2
unnamed: C2.1, U1.8 (XTAL2/PB7), Y1.1

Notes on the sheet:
Power
ISP
Detection
Confirmation
Control

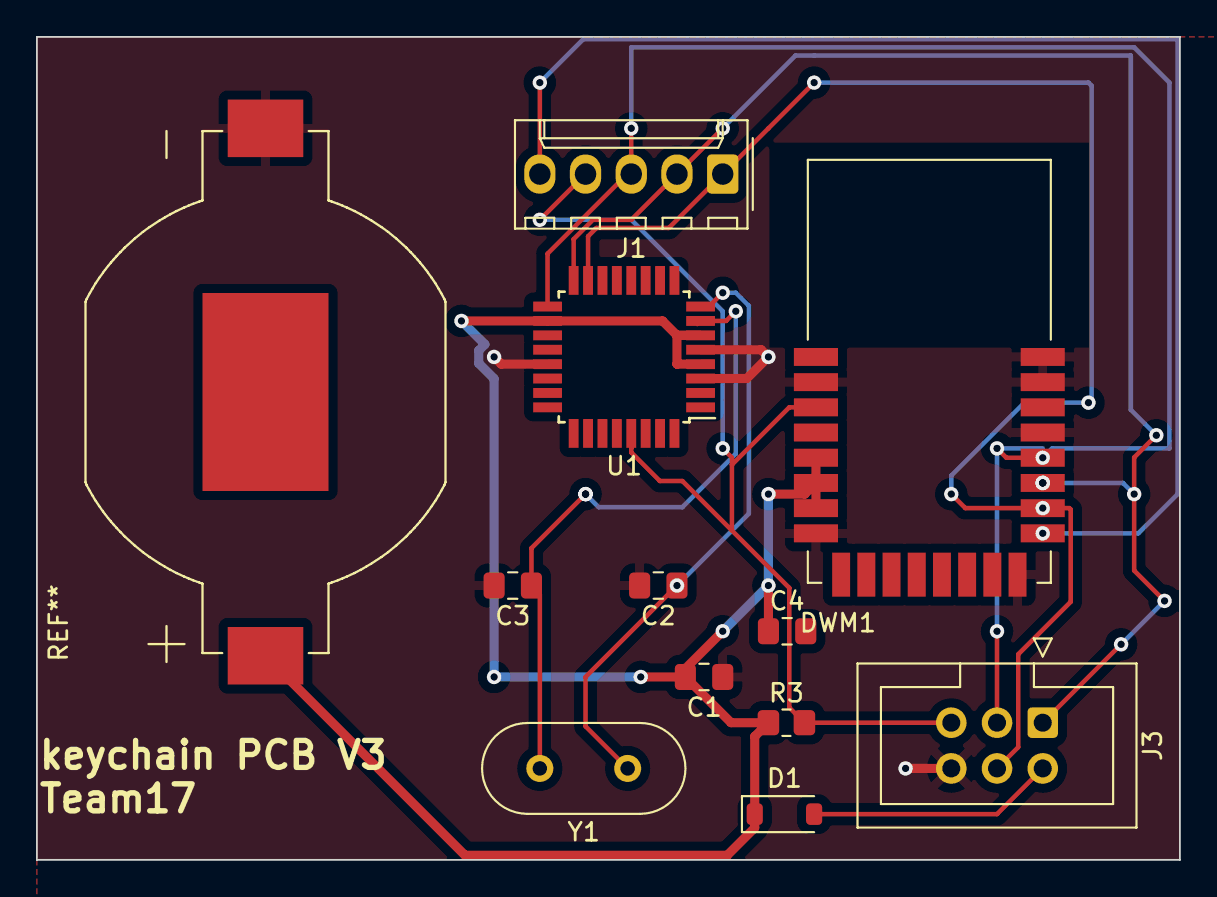
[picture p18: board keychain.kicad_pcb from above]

Board: 2 copper layers, 63.5 x 45.7 mm, 11 parts (0 on the bottom side), 10 nets.

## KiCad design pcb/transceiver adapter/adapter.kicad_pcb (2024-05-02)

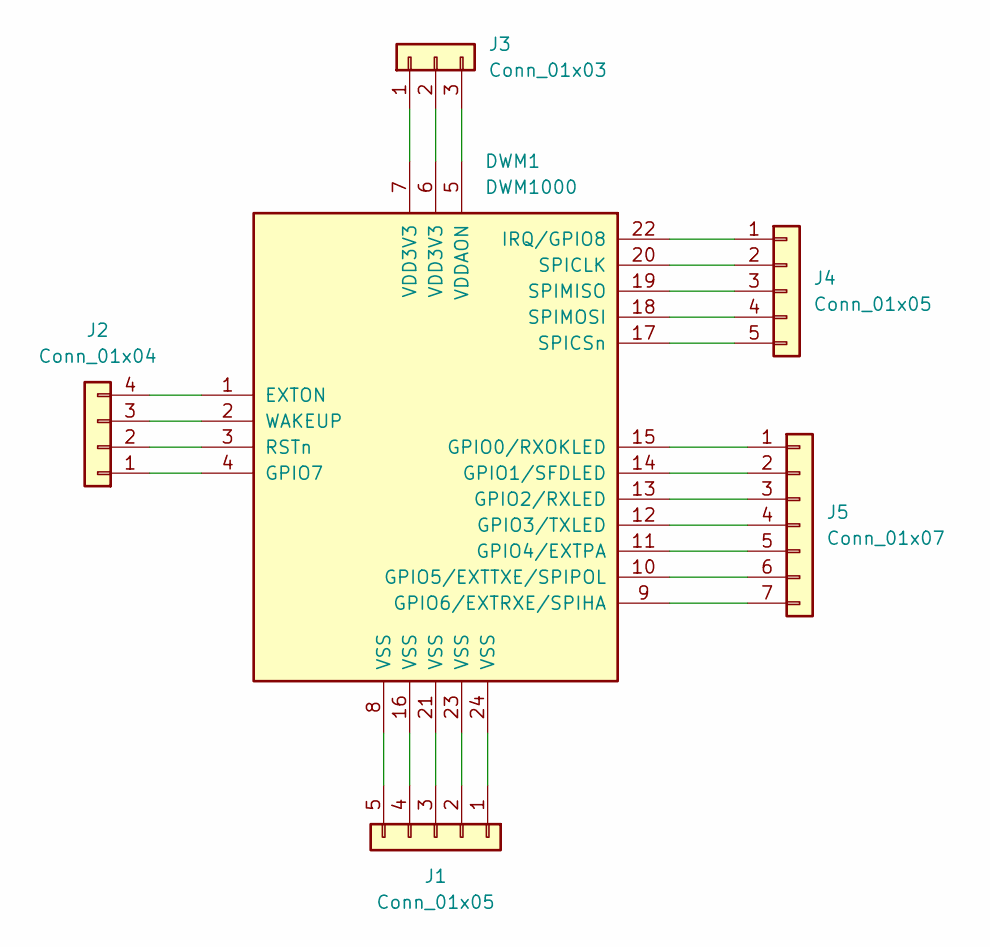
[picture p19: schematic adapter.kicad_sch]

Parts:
DWM1: DWM1000
J1, J4: Conn_01x05; Molex_KK-254_AE-6410-05A_1x05_P2.54mm_Vertical
J2: Conn_01x04; Molex_KK-254_AE-6410-04A_1x04_P2.54mm_Vertical
J3: Conn_01x03; Molex_KK-254_AE-6410-03A_1x03_P2.54mm_Vertical
J5: Conn_01x07; Molex_KK-254_AE-6410-07A_1x07_P2.54mm_Vertical

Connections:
unnamed: DWM1.1 (EXTON), J2.4
unnamed: DWM1.15 (GPIO0/RXOKLED), J5.1
unnamed: DWM1.14 (GPIO1/SFDLED), J5.2
unnamed: DWM1.13 (GPIO2/RXLED), J5.3
unnamed: DWM1.12 (GPIO3/TXLED), J5.4
unnamed: DWM1.11 (GPIO4/EXTPA), J5.5
unnamed: DWM1.10 (GPIO5/EXTTXE/SPIPOL), J5.6
unnamed: DWM1.9 (GPIO6/EXTRXE/SPIHA), J5.7
unnamed: DWM1.4 (GPIO7), J2.1
unnamed: DWM1.22 (IRQ/GPIO8), J4.1
unnamed: DWM1.3 (RSTn), J2.2
unnamed: DWM1.20 (SPICLK), J4.2
unnamed: DWM1.17 (SPICSn), J4.5
unnamed: DWM1.19 (SPIMISO), J4.3
unnamed: DWM1.18 (SPIMOSI), J4.4
unnamed: DWM1.5 (VDDAON), J3.3
unnamed: DWM1.2 (WAKEUP), J2.3
unnamed: DWM1.24 (VSS), J1.1
unnamed: DWM1.23 (VSS), J1.2
unnamed: DWM1.21 (VSS), J1.3
unnamed: DWM1.16 (VSS), J1.4
unnamed: DWM1.8 (VSS), J1.5
unnamed: DWM1.7 (VDD3V3), J3.1
unnamed: DWM1.6 (VDD3V3), J3.2

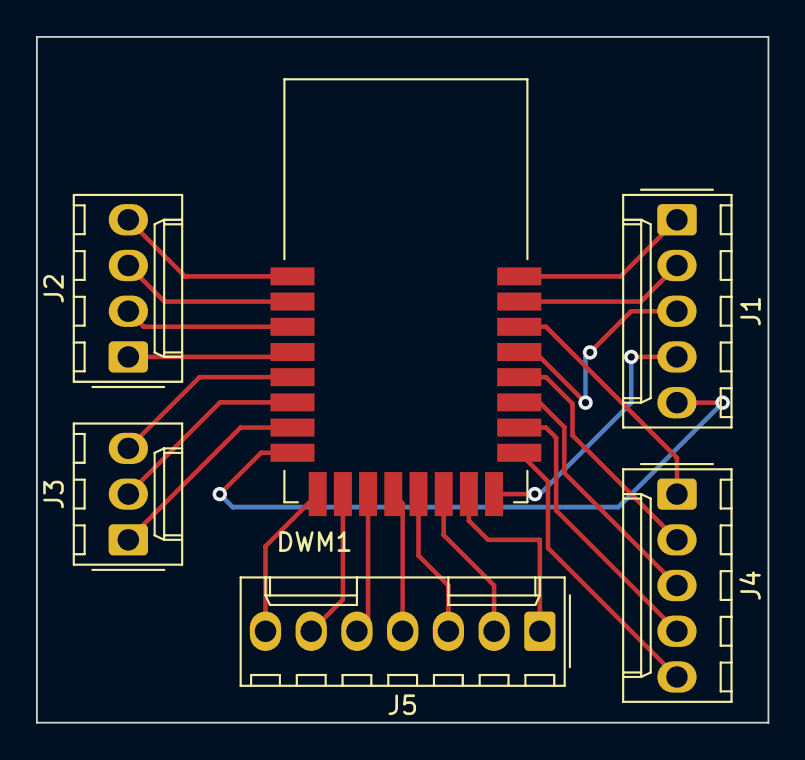
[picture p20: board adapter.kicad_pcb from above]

Board: 2 copper layers, 40.6 x 38.1 mm, 6 parts (0 on the bottom side), 24 nets.

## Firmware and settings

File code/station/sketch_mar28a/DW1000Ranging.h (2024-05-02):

/*
 * Copyright (c) 2015 by Thomas Trojer <thomas@trojer.net> and Leopold Sayous <leosayous@gmail.com>
 * Decawave DW1000 library for arduino.
 *
 * Licensed under the Apache License, Version 2.0 (the "License");
 * you may not use this file except in compliance with the License.
 * You may obtain a copy of the License at
 *
 *     http://www.apache.org/licenses/LICENSE-2.0
 *
 * Unless required by applicable law or agreed to in writing, software
 * distributed under the License is distributed on an "AS IS" BASIS,
 * WITHOUT WARRANTIES OR CONDITIONS OF ANY KIND, either express or implied.
 * See the License for the specific language governing permissions and
 * limitations under the License.
 *
 * @file DW1000Ranging.h
 * Arduino global library (header file) working with the DW1000 library
 * for the Decawave DW1000 UWB transceiver IC.
 *
 * @TODO
 * - remove or debugmode for Serial.print
 * - move strings to flash to reduce ram usage
 * - do not safe duplicate of pin settings
 * - maybe other object structure
 * - use enums instead of preprocessor constants
 */

#include "DW1000.h"
#include "DW1000Time.h"
#include "DW1000Device.h" 
#include "DW1000Mac.h"

// messages used in the ranging protocol
#define POLL 0
#define POLL_ACK 1
#define RANGE 2
#define RANGE_REPORT 3
#define RANGE_FAILED 255
#define BLINK 4
#define RANGING_INIT 5

#define LEN_DATA 90

//Max devices we put in the networkDevices array ! Each DW1000Device is 74 Bytes in SRAM memory for now.
#define MAX_DEVICES 4

//Default Pin for module:
#define DEFAULT_RST_PIN 9
#define DEFAULT_SPI_SS_PIN 10

//Default value
//in ms
#define DEFAULT_RESET_PERIOD 200
//in us
#define DEFAULT_REPLY_DELAY_TIME 7000

//sketch type (anchor or tag)
#define TAG 0
#define ANCHOR 1

//default timer delay
#define DEFAULT_TIMER_DELAY 80

//debug mode
#ifndef DEBUG
#define DEBUG false
#endif


class DW1000RangingClass {
public:
	//variables
	// data buffer
	static byte data[LEN_DATA];
	
	//initialisation
	static void    initCommunication(uint8_t myRST = DEFAULT_RST_PIN, uint8_t mySS = DEFAULT_SPI_SS_PIN, uint8_t myIRQ = 2);
	static void    configureNetwork(uint16_t deviceAddress, uint16_t networkId, const byte mode[]);
	static void    generalStart();
	static void    startAsAnchor(char address[], const byte mode[], const bool randomShortAddress = true);
	static void    startAsTag(char address[], const byte mode[], const bool randomShortAddress = true);
	static boolean addNetworkDevices(DW1000Device* device, boolean shortAddress);
	static boolean addNetworkDevices(DW1000Device* device);
	static void    removeNetworkDevices(int16_t index);
	
	//setters
	static void setReplyTime(uint16_t replyDelayTimeUs);
	static void setResetPeriod(uint32_t resetPeriod);
	
	//getters
	static byte* getCurrentAddress() { return _currentAddress; };
	
	static byte* getCurrentShortAddress() { return _currentShortAddress; };
	
	static uint8_t getNetworkDevicesNumber() { return _networkDevicesNumber; };
	
	//ranging functions
	static int16_t detectMessageType(byte datas[]); // TODO check return type
	static float loop();
	static void useRangeFilter(boolean enabled);
	// Used for the smoothing algorithm (Exponential Moving Average). newValue must be >= 2. Default 15.
	static void setRangeFilterValue(uint16_t newValue);
	
	//Handlers:
	static void attachNewRange(void (* handleNewRange)(void)) { _handleNewRange = handleNewRange; };
	
	static void attachBlinkDevice(void (* handleBlinkDevice)(DW1000Device*)) { _handleBlinkDevice = handleBlinkDevice; };
	
	static void attachNewDevice(void (* handleNewDevice)(DW1000Device*)) { _handleNewDevice = handleNewDevice; };
	
	static void attachInactiveDevice(void (* handleInactiveDevice)(DW1000Device*)) { _handleInactiveDevice = handleInactiveDevice; };
	
	
	
	static DW1000Device* getDistantDevice();
	static DW1000Device* searchDistantDevice(byte shortAddress[]);
	
	//FOR DEBUGGING
	static void visualizeDatas(byte datas[]);


private:
	//other devices in the network
	static DW1000Device _networkDevices[MAX_DEVICES];
	static volatile uint8_t _networkDevicesNumber;
	static int16_t      _lastDistantDevice;
	static byte         _currentAddress[8];
	static byte         _currentShortAddress[2];
	static byte         _lastSentToShortAddress[2];
	static DW1000Mac    _globalMac;
	static int32_t      timer;
	static int16_t      counterForBlink;
	
	//Handlers:
	static void (* _handleNewRange)(void);
	static void (* _handleBlinkDevice)(DW1000Device*);
	static void (* _handleNewDevice)(DW1000Device*);
	static void (* _handleInactiveDevice)(DW1000Device*);
	
	//sketch type (tag or anchor)
	static int16_t          _type; //0 for tag and 1 for anchor
	// TODO check type, maybe enum?
	// message flow state
	static volatile byte    _expectedMsgId;
	// message sent/received state
	static volatile boolean _sentAck;
	static volatile boolean _receivedAck;
	// protocol error state
	static boolean          _protocolFailed;
	// reset line to the chip
	static uint8_t     _RST;
	static uint8_t     _SS;
	// watchdog and reset period
	static uint32_t    _lastActivity;
	static uint32_t    _resetPeriod;
	// reply times (same on both sides for symm. ranging)
	static uint16_t     _replyDelayTimeUS;
	//timer Tick delay
	static uint16_t     _timerDelay;
	// ranging counter (per second)
	static uint16_t     _successRangingCount;
	static uint32_t    _rangingCountPeriod;
	//ranging filter
	static volatile boolean _useRangeFilter;
	static uint16_t         _rangeFilterValue;
	//_bias correction
	static char  _bias_RSL[17]; // TODO remove or use
	//17*2=34 bytes in SRAM
	static int16_t _bias_PRF_16[17]; // TODO remove or use
	//17 bytes in SRAM
	static char  _bias_PRF_64[17]; // TODO remove or use
	
	
	//methods
	static void handleSent();
	static void handleReceived();
	static void noteActivity();
	static void resetInactive();
	
	//global functions:
	static void checkForReset();
	static void checkForInactiveDevices();
	static void copyShortAddress(byte address1[], byte address2[]);
	
	//for ranging protocole (ANCHOR)
	static void transmitInit();
	static void transmit(byte datas[]);
	static void transmit(byte datas[], DW1000Time time);
	static void transmitBlink();
	static void transmitRangingInit(DW1000Device* myDistantDevice);
	static void transmitPollAck(DW1000Device* myDistantDevice);
	static void transmitRangeReport(DW1000Device* myDistantDevice);
	static void transmitRangeFailed(DW1000Device* myDistantDevice);
	static void receiver();
	
	//for ranging protocole (TAG)
	static void transmitPoll(DW1000Device* myDistantDevice);
	static void transmitRange(DW1000Device* myDistantDevice);
	
	//methods for range computation
	static void computeRangeAsymmetric(DW1000Device* myDistantDevice, DW1000Time* myTOF);
	
	static void timerTick();
	
	//Utils
	static float filterValue(float value, float previousValue, uint16_t numberOfElements);
};

extern DW1000RangingClass DW1000Ranging;

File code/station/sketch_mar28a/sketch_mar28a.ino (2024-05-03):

#include <SPI.h>
#include "DW1000.h"
#include "DW1000CompileOptions.h"
#include "DW1000Constants.h"
#include "DW1000Device.h"
#include "DW1000Mac.h"
#include "DW1000Ranging.h"
#include "DW1000Time.h"
#include "require_cpp11.h"

#define DETECTION_RADIUS 5

#define SLEEP_DEBUG 3
#define TIMER_DEBUG 4
#define WAITING_DEBUG 5
#define ALARM_DEBUG 6
#define BUTTON_PIN 7

#define PRESSURE_DEBUG A5

// void newRange();
// void newBlink(DW1000Device* device);
// void inactiveDevice(DW1000Device* device);

// transcevier pins
// connection pins
const uint8_t PIN_RST = 9; // reset pin
const uint8_t PIN_IRQ = 2; // irq pin
const uint8_t PIN_SS = SS; // spi select pin

// Threshold for the force resistor's reading to switch from SLEEP to TIMER state
unsigned long timestamp = 0;
unsigned long transceiver_timer = 0;

bool inside_radius = false;
bool inside_radius_timer = false;


// Define an enum for the system states
enum SystemState {
  SLEEP,
  TIMER,
  WAITING,
  ALARM
};

// Global variable to hold the current state of the system
SystemState systemState = SLEEP;

void setup() {  
  // // Set the transceiver CS pin as an output:
  // pinMode(TRANSCEIVER_CS_PIN, OUTPUT);

  // // Set the CS pin high to start with the transceiver not selected
  // digitalWrite(TRANSCEIVER_CS_PIN, HIGH);
  transceiverSetup();
  
  // Configure the button pin as an input with an internal pull-up resistor
  pinMode(BUTTON_PIN, INPUT_PULLUP);

  // pinMode(SPEAKER_PIN, OUTPUT);

  pinMode(SLEEP_DEBUG, OUTPUT);
  pinMode(TIMER_DEBUG, OUTPUT);
  pinMode(WAITING_DEBUG, OUTPUT);
  pinMode(ALARM_DEBUG, OUTPUT);

  pinMode(PRESSURE_DEBUG, INPUT_PULLUP);

  Serial.println("Finished configuration");

}

void newRange() {
  Serial.print("from: "); Serial.print(DW1000Ranging.getDistantDevice()->getShortAddress(), HEX);
  Serial.print("\t Range: "); Serial.print(DW1000Ranging.getDistantDevice()->getRange()); Serial.print(" m");
  Serial.print("\t RX power: "); Serial.print(DW1000Ranging.getDistantDevice()->getRXPower()); Serial.println(" dBm");
}

void newBlink(DW1000Device* device) {
  Serial.print("blink; 1 device added ! -> ");
  Serial.print(" short:");
  Serial.println(device->getShortAddress(), HEX);
}

void inactiveDevice(DW1000Device* device) {
  Serial.print("delete inactive device: ");
  Serial.println(device->getShortAddress(), HEX);
}

void transceiverSetup(){
  Serial.begin(115200);
  delay(1000);
  //init the configuration
  DW1000Ranging.initCommunication(PIN_RST, PIN_SS, PIN_IRQ); //Reset, CS, IRQ pin
  //define the sketch as anchor. It will be great to dynamically change the type of module
  DW1000Ranging.attachNewRange(newRange);
  DW1000Ranging.attachBlinkDevice(newBlink);
  DW1000Ranging.attachInactiveDevice(inactiveDevice);
  //Enable the filter to smooth the distance
  //DW1000Ranging.useRangeFilter(true);
  
  //we start the module as an anchor
  DW1000Ranging.startAsAnchor("82:17:5B:D5:A9:9A:E2:9C", DW1000.MODE_LONGDATA_RANGE_ACCURACY);
  delay(1000);
}

void printState(SystemState state) {
    switch (state) {
        case SLEEP:
            Serial.println("SLEEP");
            break;
        case TIMER:
            Serial.println("TIMER");
            break;
        case WAITING:
            Serial.println("WAITING");
            break;
        case ALARM:
            Serial.println("ALARM");
            break;
        default:
            Serial.println("UNKNOWN");
            break;
    }
}



void loop() {

  unsigned long current_time = millis();

  // Read the button state
  bool buttonPressed = digitalRead(BUTTON_PIN);

  // bool pressureRead = digitalRead(PRESSURE_DEBUG) == HIGH;
  bool pressureRead = analogRead(PRESSURE_DEBUG) > 100;

  float distance = DW1000Ranging.loop();
  Serial.println(distance);

  // printState(systemState);

  // Serial.println("System is in: " + systemState);
  // Serial.println(analogRead(PRESSURE_DEBUG) > 100);


  switch (systemState) {
    case SLEEP:     
      // // Check if the pressure is below the threshold
      digitalWrite(SLEEP_DEBUG, HIGH);

      if(pressureRead){
        timestamp = millis();
        digitalWrite(SLEEP_DEBUG, LOW);
        systemState = TIMER;
        break;
      }

      break;
      
    case TIMER:
      // Perform actions for STATE_2
      digitalWrite(TIMER_DEBUG, HIGH);

      // Barrier for the code to wait 5 seconds before continuing
      if(current_time - timestamp < 5000){
        break;
      }

      if(!pressureRead){
        digitalWrite(TIMER_DEBUG, LOW);
        systemState = SLEEP;
        break;
      }else{
        digitalWrite(TIMER_DEBUG, LOW);
        systemState = WAITING;
        timestamp = millis();
        break;
      }
      break;
    case WAITING:
      digitalWrite(WAITING_DEBUG, HIGH);
      // Serial.println("INSIDE WAITING STATE");
      // distance = pollKeychain();

      if (! pressureRead){
        digitalWrite(WAITING_DEBUG, LOW);
        systemState = SLEEP;
        break;
      }
      
      if (distance > 0 && distance < DETECTION_RADIUS || inside_radius){
        inside_radius == true;

        if (inside_radius_timer == false){
          inside_radius_timer = true;
          timestamp = millis();
          break;
        }
        
        // This is a barrier that allows the waiting state to wait X seconds after detecting the keys in the radius before switching to the alarm state
        if(current_time - timestamp < 10000){
          break;
        }

        inside_radius_timer = false;

        if (! pressureRead){ // if the keys were placed into the dish, switch to sleep
          digitalWrite(WAITING_DEBUG, LOW);
          inside_radius = false;
          systemState = SLEEP;
          break;
        }

        if (distance > 0 && distance < DETECTION_RADIUS){ // still in the vicinity after 5 seconds, switch to alarm state
          digitalWrite(WAITING_DEBUG, LOW);
          inside_radius = false;
          systemState = ALARM;
          break;
        }
      }
      break;
    case ALARM:
      analogWrite(ALARM_DEBUG, 245); // Set the pin high
      // delay(30); // Wait for half the period (25ms for a 400Hz square wave)
      // analogWrite(ALARM_DEBUG, 1500); // Set the pin low
      // delay(30); // Wait for the other half of the period

      if(!pressureRead){
        digitalWrite(ALARM_DEBUG, LOW);
        systemState = SLEEP;
        break;
      }else if (buttonPressed){
        digitalWrite(ALARM_DEBUG, LOW);
        timestamp = millis();
        systemState = TIMER;
        break;
      }
      break;
  }
  // Add any other state-independent actions here
  // delay(100);
}

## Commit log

2024-02-29 add pcb
    [habit-forming key-station.kicad_sch]
2024-03-19 keystation pcb
    [habit-forming key-station.kicad_pcb, key.kicad_pcb, key.kicad_sch]
2024-03-19 keychain pcb
    [keychain.kicad_pcb, keychain.kicad_sch]
2024-03-26 update pcb
    [key.kicad_pcb, key.kicad_sch]
2024-03-26 generated week 3 gerbers
    [key-B_Cu.gbl, key-B_Mask.gbs, key-B_Paste.gbp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]
2024-03-31 adapter added
    [BU2032SM-HD-G.step, adapter.kicad_pcb, adapter.kicad_sch]
2024-04-03 dish pcb updated
    [key.kicad_pcb, key.kicad_sch]
2024-04-15 debugging ranging code
    [adapter-B_Cu.gbr, adapter-B_Mask.gbr, adapter-B_Paste.gbr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]
